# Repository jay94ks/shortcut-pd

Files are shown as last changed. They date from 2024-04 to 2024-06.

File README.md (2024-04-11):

# Simple Shortcut Keypad.
 This has six keys that are customizable, and this designed for disabled peoples. I'm working with disabled brother. he's a survivor of car-crash in highway, I don't know details. A few days ago, I asked him how to press `Ctrl + Alt + Del` key combinations, he answered that "I've gave up to press these kind of key combinations, forever". I thought that, if there is a special keyboard to help him, he will never need to give up to press complex key combinations. this project is for that.
 of course, this is also for gamers and quick `NSFW`, haha!

## Boards
This project is consisted of two boards. one is a USB hub port and `RP2040` board and other one is keypad board. this two boards are connected through `FPC` cable. and fixed by steel bolt bars.

### Lower board
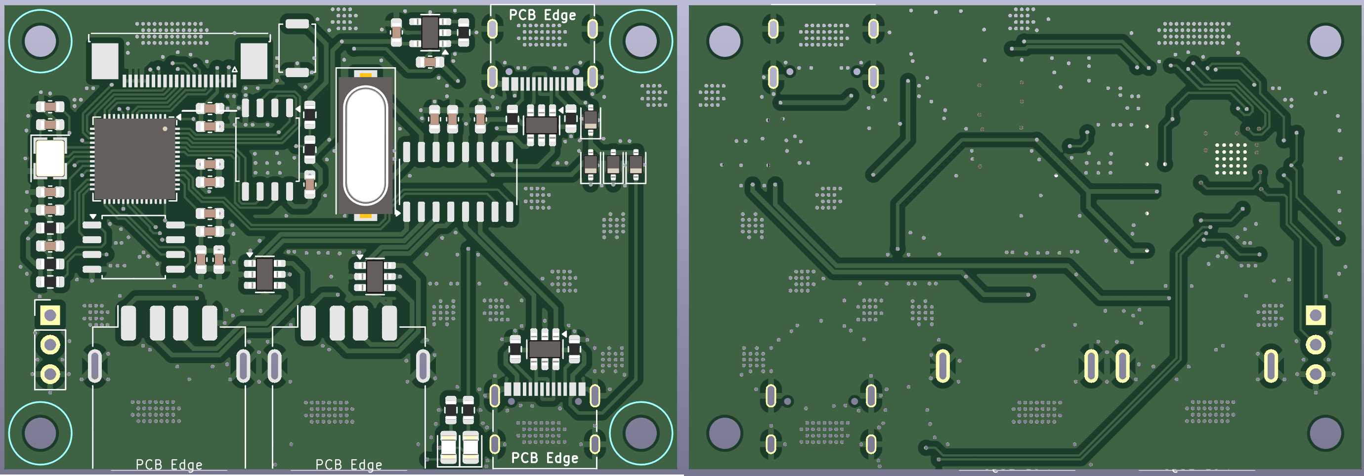
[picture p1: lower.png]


### Upper board
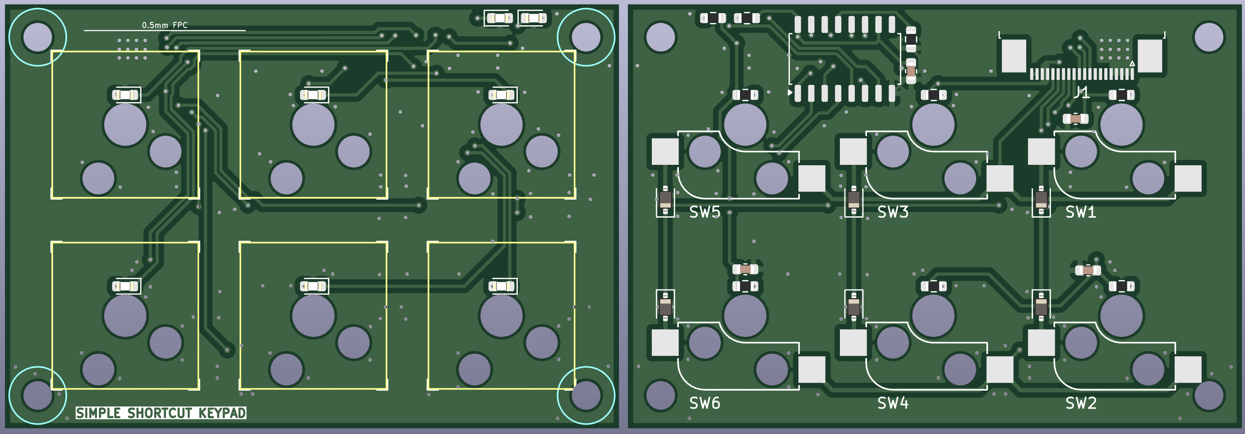
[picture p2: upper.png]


### Assembly diagram
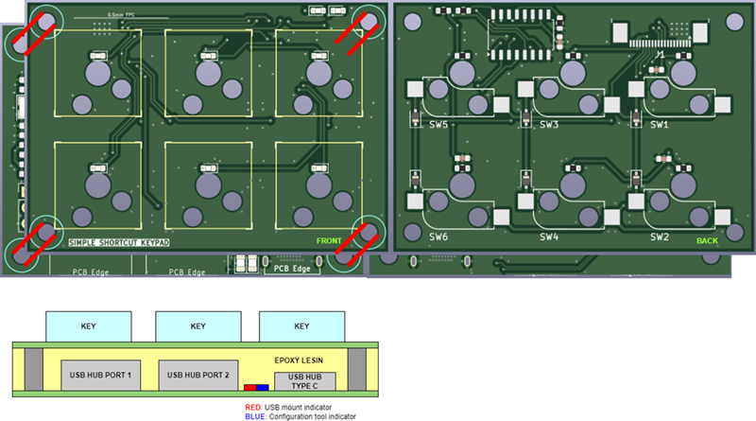
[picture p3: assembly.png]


## Firmware
Work in progress

## Configuration Tool
Work in progress

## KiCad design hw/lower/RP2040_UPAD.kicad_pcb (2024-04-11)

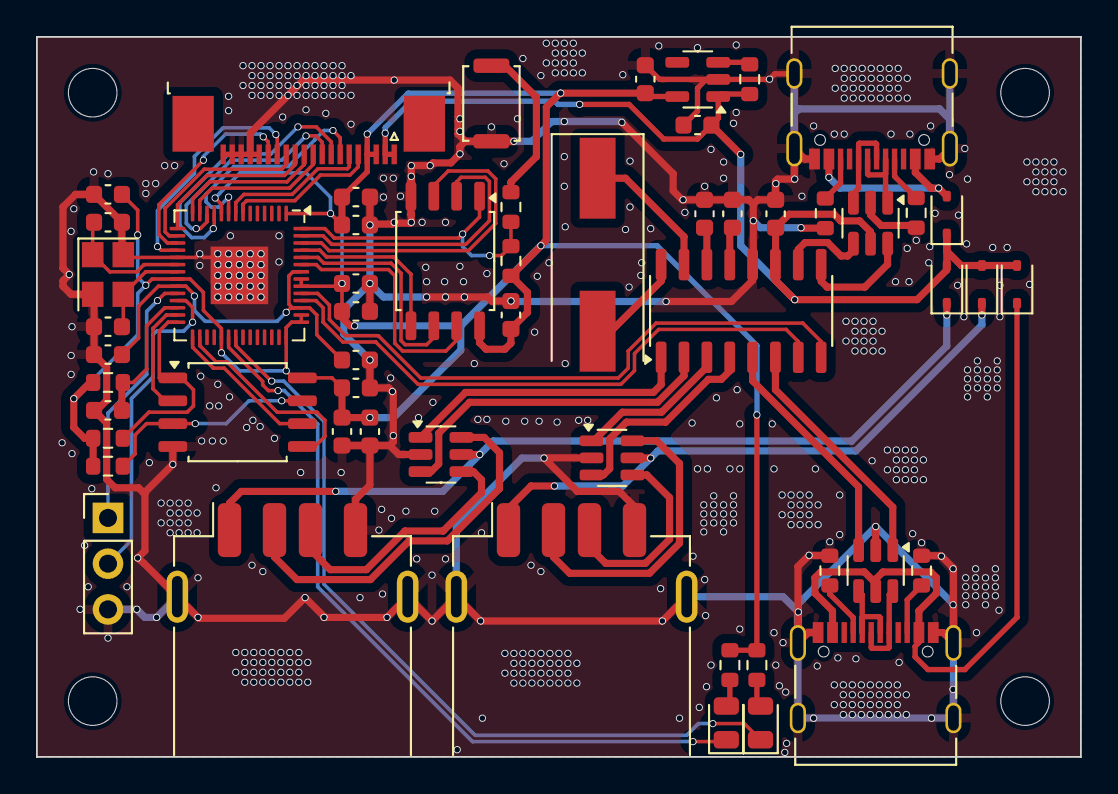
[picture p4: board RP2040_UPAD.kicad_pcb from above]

Board: 2 copper layers, 58.0 x 40.0 mm, 59 parts (0 on the bottom side), 67 nets.

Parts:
C1, C8, C9, C10, C11, C13, C14, C15, C16: 100nF; C_0603_1608Metric
C2, C3: 30pF; C_0603_1608Metric
C5, C6, C7: 2.2uF; C_0603_1608Metric
C17, C18, C19, C20, C21: 10uF; C_0603_1608Metric
D1: LED/R; LED_0805_2012Metric
D2: LED/B; LED_0805_2012Metric
D3, D4, D6, D9: 1N5819WS; D_SOD-323
H1, H2, H3, H4: MountingHole; MountingHole_2.7mm_M2.5
J1: JTAG; PinHeader_1x03_P2.54mm_Vertical
J2, J5: USB_C_Receptacle_USB2.0; USB_C_Receptacle_Palconn_UTC16-G
J3, J4: USB_A; USB_A_Receptacle_GCT_USB1046
J6: 0.5mm FPC; TE_2-1734839-0_1x20-1MP_P0.5mm_Horizontal
R3: 100; R_0603_1608Metric
R4, R7, R10, R12: 10k; R_0603_1608Metric
R5, R6: 1k; R_0603_1608Metric
R11: 100k; R_0603_1608Metric
R13, R14, R18, R19: 5.1k; R_0603_1608Metric
SW1: SW_Push; SW_Push_SPST_NO_Alps_SKRK
U1: RP2040; QFN-56-1EP_7x7mm_P0.4mm_EP3.2x3.2mm
U2: W25Q128JVSS; SOIC-8_5.23x5.23mm_P1.27mm
U3: XC6220B331MR; SOT-23-5
U4: W25Q32JVSS; SOIC-8_5.23x5.23mm_P1.27mm
U5, U11, U12, U13: USBLC6-2SC6; SOT-23-6
U6: SL2.1A; SO-16_3.9x9.9mm_P1.27mm
Y1: 12MHz; Crystal_SMD_3225-4Pin_3.2x2.5mm
Y2: 12MHz; Crystal_SMD_HC49-SD

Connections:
+1V1: C5.2, C6.2, U1.23 (DVDD), U1.45 (VREG_VOUT), U1.50 (DVDD)
+3.3VD: C7.1, C8.1, C9.1, C10.1, C11.1, C13.1, C14.1, C15.1, C16.1, C18.1, J6.3, J6.4, R4.2, R5.2, R6.2, R7.1, R10.2, R12.1, U1.1 (IOVDD), U1.10 (IOVDD), U1.22 (IOVDD), U1.33 (IOVDD), U1.42 (IOVDD), U1.43 (ADC_AVDD), U1.44 (VREG_IN), U1.48 (USB_VDD), U1.49 (IOVDD), U2.8 (VCC), U3.5 (VOUT), U4.8 (VCC)
+5VD: C17.1, C21.1, D3.1 (K), D4.2 (A), D6.2 (A), D9.2 (A), J6.1, J6.2, R11.2, U3.1 (VIN), U5.5 (VBUS), U6.11 (VDD5)
/RP2040/QSPI_SCLK: U1.52 (QSPI_SCLK), U2.6 (CLK)
/RP2040/QSPI_SD0: U1.53 (QSPI_SD0), U2.5 (DI(IO0))
/RP2040/QSPI_SD1: U1.55 (QSPI_SD1), U2.2 (DO(IO1))
/RP2040/QSPI_SD2: U1.54 (QSPI_SD2), U2.3 (IO2)
/RP2040/QSPI_SD3: U1.51 (QSPI_SD3), U2.7 (IO3)
/RP2040/QSPI_SS: R3.1, R7.2, U1.56 (QSPI_SS), U2.1 (~CS)
/USB/USB_RAW_DM: J2.A7 (D-), J2.B7 (D-), U5.1 (I/O1)
/USB/USB_RAW_DP: J2.A6 (D+), J2.B6 (D+), U5.3 (I/O2)
GND: C1.2, C2.1, C3.1, C5.1, C6.1, C7.2, C8.2, C9.2, C10.2, C11.2, C13.2, C14.2, C15.2, C16.2, C17.2, C18.2, C19.1, C20.1, C21.2, J1.3, J2.A1 (GND), J2.A12 (GND), J2.B1 (GND), J2.B12 (GND), J2.S1 (SHIELD), J3.4 (GND), J3.5 (Shield), J4.4 (GND), J4.5 (Shield), J5.A1 (GND), J5.A12 (GND), J5.B1 (GND), J5.B12 (GND), J5.S1 (SHIELD), J6.16, J6.17, J6.18, J6.19, J6.20, R13.2, R14.1, R18.2, R19.1, SW1.1, U1.19 (TESTEN), U1.57 (GND), U2.4 (GND), U3.2 (GND), U4.4 (GND), U5.2 (GND), U6.12 (GND), U11.2 (GND), U12.2 (GND), U13.2 (GND), Y1.2, Y1.4
GP5/ROW1: J6.5, U1.7 (GPIO5)
GP6/ROW2: J6.6, U1.8 (GPIO6)
GP7/COL1: J6.7, U1.9 (GPIO7)
GP8/COL2: J6.8, U1.11 (GPIO8)
GP9/COL3: J6.9, U1.12 (GPIO9)
GP10/SPI1_SCK: J6.10, U1.13 (GPIO10)
GP11/SPI1_TX: J6.11, U1.14 (GPIO11)
GP12/SPI1_RX: J6.12, U1.15 (GPIO12)
GP13/SPI1_CSn: J6.13, U1.16 (GPIO13)
GP14/I2C1_SDA: J6.15, U1.17 (GPIO14)
GP15/I2C1_SCL: J6.14, U1.18 (GPIO15)
GP16/SPI0_RX: U1.27 (GPIO16), U4.2 (DO(IO1))
GP17/SPI0_CSn: R12.2, U1.28 (GPIO17), U4.1 (~CS)
GP18/SPI0_SCK: U1.29 (GPIO18), U4.6 (CLK)
GP19/SPI0_TX: U1.30 (GPIO19), U4.5 (DI(IO0))
GP22/LED_CR: D1.1 (K), U1.34 (GPIO22)
GP23/LED_CE: D2.1 (K), U1.35 (GPIO23)
unnamed: D1.2 (A), R5.1
unnamed: D2.2 (A), R6.1
unnamed: D4.1 (K), J5.A4 (VBUS), J5.A9 (VBUS), J5.B4 (VBUS), J5.B9 (VBUS), U13.5 (VBUS)
unnamed: D6.1 (K), J3.1 (VBUS), U11.5 (VBUS)
unnamed: D9.1 (K), J4.1 (VBUS), U12.5 (VBUS)
unnamed: J2.A5 (CC1), R13.1
unnamed: J2.B5 (CC2), R14.2
unnamed: J3.3 (D+), U11.4 (I/O2)
unnamed: J3.2 (D-), U11.6 (I/O1)
unnamed: J4.3 (D+), U12.4 (I/O2)
unnamed: J4.2 (D-), U12.6 (I/O1)
unnamed: J5.A5 (CC1), R18.1
unnamed: J5.B5 (CC2), R19.2
unnamed: J5.A6 (D+), J5.B6 (D+), U13.6 (I/O1)
unnamed: J5.A7 (D-), J5.B7 (D-), U13.4 (I/O2)
unnamed: R3.2, SW1.2
unnamed: C2.2, U1.20 (XIN), Y1.1
unnamed: C3.2, U1.21 (XOUT), Y1.3
unnamed: R11.1, U3.3 (CE)
unnamed: R10.1, U4.3 (IO2), U4.7 (IO3)
unnamed: C19.2, U6.14 (VDD18)
unnamed: C20.2, U6.13 (VDD33)
unnamed: U6.16 (XIN), Y2.2
unnamed: U6.15 (XOUT), Y2.1
RP2040_DM: U1.46 (USB_DM), U6.7 (DM1)
RP2040_DP: U1.47 (USB_DP), U6.8 (DP1)
RUN: C1.1, R4.1, U1.26 (RUN)
SWD_CLK: J1.1, U1.24 (SWCLK)
SWD_DIO: J1.2, U1.25 (SWD)
USBH1_DM: U6.3 (DM3), U11.1 (I/O1)
USBH1_DP: U6.4 (DP3), U11.3 (I/O2)
USBH2_DM: U6.1 (DM4), U12.1 (I/O1)
USBH2_DP: U6.2 (DP4), U12.3 (I/O2)
USBM2_DM: U6.5 (DM2), U13.3 (I/O2)
USBM2_DP: U6.6 (DP2), U13.1 (I/O1)
USB_DM: U5.6 (I/O1), U6.9 (DM)
USB_DP: U5.4 (I/O2), U6.10 (DP)
VBUS: D3.2 (A), J2.A4 (VBUS), J2.A9 (VBUS), J2.B4 (VBUS), J2.B9 (VBUS)

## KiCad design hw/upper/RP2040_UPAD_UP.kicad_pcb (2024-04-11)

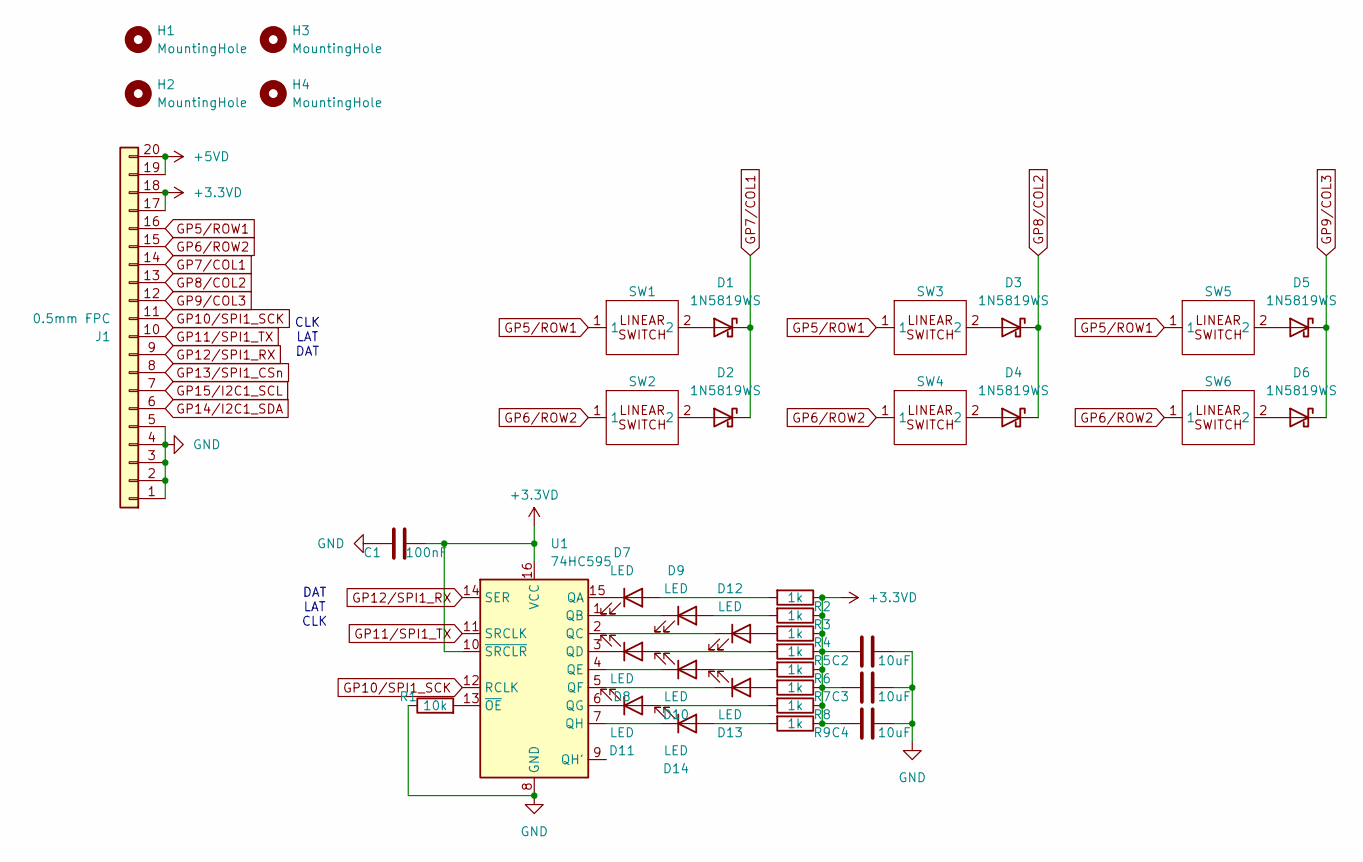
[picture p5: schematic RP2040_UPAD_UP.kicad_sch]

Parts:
C1: 100nF; C_0603_1608Metric
C2, C3, C4: 10uF; C_0603_1608Metric
D1, D2, D3, D4, D5, D6: 1N5819WS; D_SOD-323
D7, D8, D9, D10, D11, D12, D13, D14: LED; LED_0603_1608Metric
H1, H2, H3, H4: MountingHole; MountingHole_2.7mm_M2.5
J1: 0.5mm FPC; TE_2-1734839-0_1x20-1MP_P0.5mm_Horizontal
R1: 10k; R_0603_1608Metric
R2, R3, R4, R5, R6, R7, R8, R9: 1k; R_0603_1608Metric
SW1, SW2, SW3, SW4, SW5, SW6: Kailh_socket_MX_no_throughole
U1: 74HC595; SOP-16_4.55x10.3mm_P1.27mm

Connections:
+3.3VD: C1.2, C2.1, C3.1, C4.1, J1.17, J1.18, R2.1, R3.1, R4.1, R5.1, R6.1, R7.1, R8.1, R9.1, U1.10 (~SRCLR), U1.16 (VCC)
+5VD: J1.19, J1.20
GND: C1.1, C2.2, C3.2, C4.2, J1.1, J1.2, J1.3, J1.4, J1.5, R1.1, U1.8 (GND)
GP5/ROW1: J1.16, SW1.1, SW3.1, SW5.1
GP6/ROW2: J1.15, SW2.1, SW4.1, SW6.1
GP7/COL1: D1.1 (K), D2.1 (K), J1.14
GP8/COL2: D3.1 (K), D4.1 (K), J1.13
GP9/COL3: D5.1 (K), D6.1 (K), J1.12
GP10/SPI1_SCK: J1.11, U1.12 (RCLK)
GP11/SPI1_TX: J1.10, U1.11 (SRCLK)
GP12/SPI1_RX: J1.9, U1.14 (SER)
GP13/SPI1_CSn: J1.8
GP14/I2C1_SDA: J1.6
GP15/I2C1_SCL: J1.7
unnamed: D1.2 (A), SW1.2
unnamed: D2.2 (A), SW2.2
unnamed: D3.2 (A), SW3.2
unnamed: D4.2 (A), SW4.2
unnamed: D5.2 (A), SW5.2
unnamed: D6.2 (A), SW6.2
unnamed: D7.2 (A), R2.2
unnamed: D7.1 (K), U1.15 (QA)
unnamed: D8.2 (A), R5.2
unnamed: D8.1 (K), U1.3 (QD)
unnamed: D9.2 (A), R3.2
unnamed: D9.1 (K), U1.1 (QB)
unnamed: D10.2 (A), R6.2
unnamed: D10.1 (K), U1.4 (QE)
unnamed: D11.2 (A), R8.2
unnamed: D11.1 (K), U1.6 (QG)
unnamed: D12.2 (A), R4.2
unnamed: D12.1 (K), U1.2 (QC)
unnamed: D13.2 (A), R7.2
unnamed: D13.1 (K), U1.5 (QF)
unnamed: D14.2 (A), R9.2
unnamed: D14.1 (K), U1.7 (QH)
unnamed: R1.2, U1.13 (~OE)

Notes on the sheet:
CLK LAT DAT
DAT LAT CLK

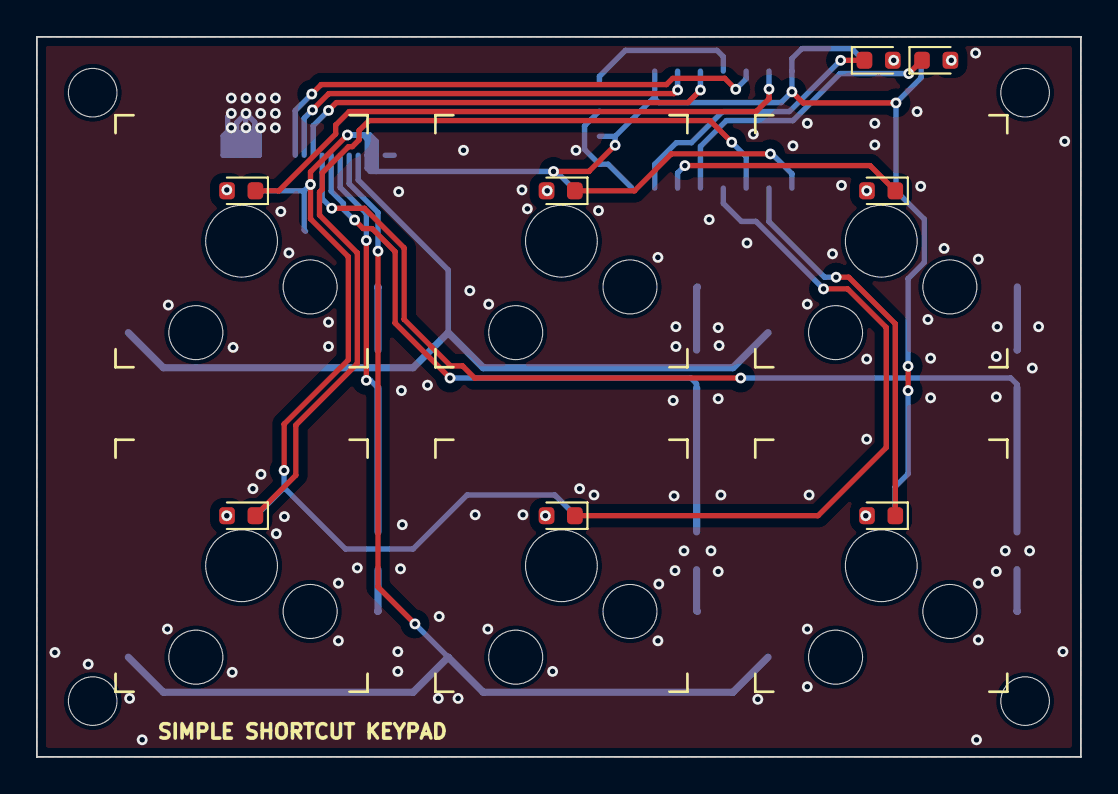
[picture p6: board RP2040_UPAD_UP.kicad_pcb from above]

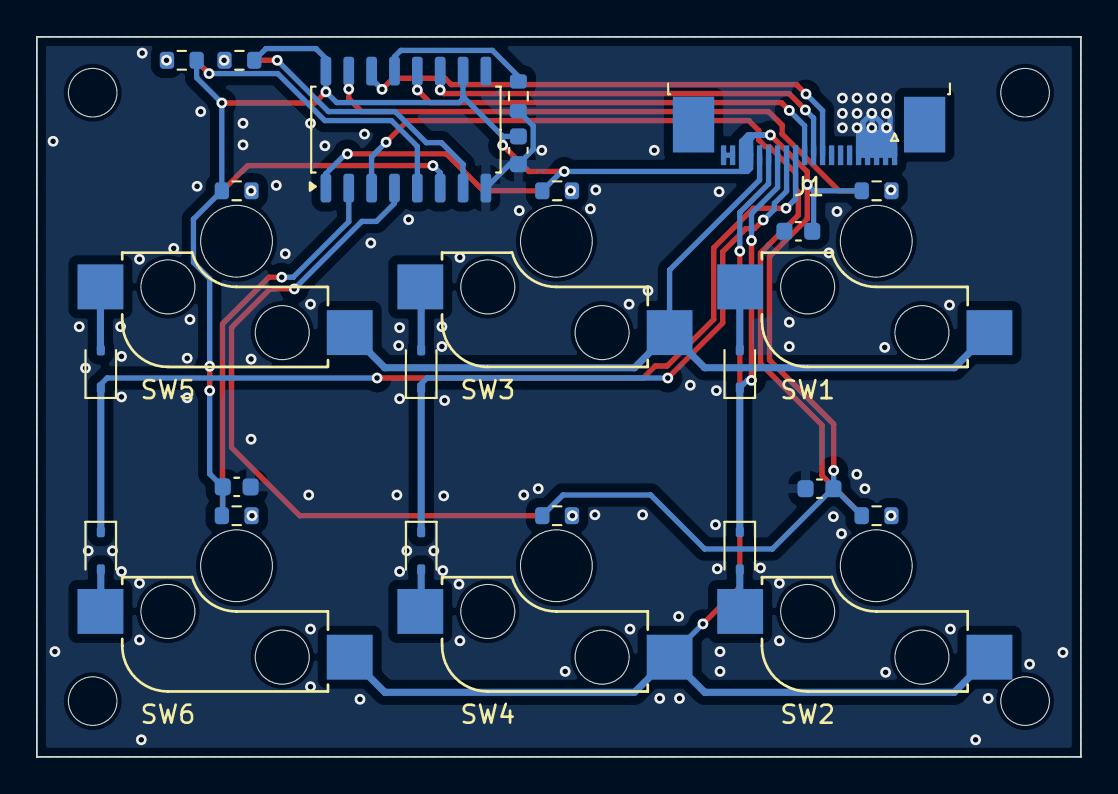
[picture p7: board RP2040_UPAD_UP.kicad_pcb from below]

Board: 2 copper layers, 58.0 x 40.0 mm, 39 parts (21 on the bottom side), 34 nets.

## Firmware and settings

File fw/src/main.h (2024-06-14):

#ifndef __MAIN_H__
#define __MAIN_H__

enum {

    EGPIO_ROW1 = 5,
    EGPIO_ROW2 = 6,
    EGPIO_COL1 = 7,
    EGPIO_COL2 = 8,
    EGPIO_COL3 = 9,

    EGPIO_595_LAT = 10,
    EGPIO_595_CLK = 11,
    EGPIO_595_DAT = 12,

    EGPIO_SPI0_RX = 16,
    EGPIO_SPI0_CSn = 17,
    EGPIO_SPI0_SCK = 18,
    EGPIO_SPI0_TX = 19,

    EGPIO_LED_CR = 22,      // --> USB mount.
    EGPIO_LED_CE = 23,      // --> USB config.

    EGPIO_VSENS = 29
    
};

enum EKey {
    EKEY_00 = 0,
    EKEY_01,
    EKEY_02,
    EKEY_10,
    EKEY_11,
    EKEY_12,
    EKEY_MAX,
    EKEY_INV = 0xff,
};

enum ELed {
    ELED_00 = 7,
    ELED_01 = 6,
    ELED_02 = 1,
    ELED_10 = 4,
    ELED_11 = 3,
    ELED_12 = 5,
    ELED_TR = 2,    // --> D13. CAPSLOCK
    ELED_TL = 0     // --> D14. NUMLOCK
};

#endif

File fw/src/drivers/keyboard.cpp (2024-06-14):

#include "keyboard.h"
#include <string.h>
#include <hardware/gpio.h>
#include <bsp/board_api.h>

const uint8_t Keyboard::PIN_ROW[MAX_ROW] = {
    EGPIO_ROW1, EGPIO_ROW2
};

const uint8_t Keyboard::PIN_COL[MAX_COL] = {
    EGPIO_COL1, EGPIO_COL2, EGPIO_COL3
};

EKey KeyOrderIterator::operator*() const {
    if (_kbd) {
        return _kbd->getKeyInOrder(_cur);
    }

    return EKEY_INV;
}

Keyboard::Keyboard() {
    for(uint8_t i = 0; i < MAX_ROW; ++i) {
        const uint8_t pin = PIN_ROW[i];

        gpio_init(pin);
        gpio_set_dir(pin, GPIO_OUT);
        gpio_put(pin, 0);
    }

    for(uint8_t i = 0; i < MAX_COL; ++i) {
        const uint8_t pin = PIN_COL[i];

        gpio_init(pin);
        gpio_set_dir(pin, GPIO_IN);
    }

    memset(_next, 0, sizeof(_next));
    memset(_state, 0, sizeof(_state));
    
    _ordered = 0;
    _scantick = 0;

    for(uint8_t i = 0; i < EKEY_MAX; ++i) {
        _orders[i] = EKEY_INV;
    }
}

void Keyboard::scanOnce() {
    const uint32_t now = board_millis();
    if (_scantick != now) {
        _scantick = now;

        memset(_next, 0, sizeof(_next));

        // --> scan line levels.
        for(uint8_t i = 0; i < MAX_ROW; ++i) {
            const uint8_t row = PIN_ROW[i];
            
            gpio_put(row, 1);
            delayNs();

            for(uint8_t j = 0; j < MAX_COL; ++j) {
                const uint8_t mask = 1 << j;

                if (gpio_get(PIN_COL[j])) {
                    _next[i] |= mask;
                }
            }

            gpio_put(row, 0);
            delayNs();
        }
    }
    
    updateOnce();
}

void Keyboard::updateOnce() {
    // --> summarize key changes.
    for(uint8_t row = 0; row < MAX_ROW; ++row) { 
        const uint8_t offset = row * MAX_COL;

        for(uint8_t col = 0; col < MAX_COL; ++col) {
            const EKey key = EKey(offset + col);
            const uint8_t mask = 1 << col;

            const uint8_t prev 
                = _state[key].ls == EKSL_RISE || 
                  _state[key].ls == EKSL_HIGH;

            const uint8_t next = (_next[row] & mask) != 0;
            
            if (prev != next) {
                if (next) {
                    _state[key].ls = EKSL_RISE;
                    addOrder(key);
                } else {
                    _state[key].ls = EKSL_FALL;
                    removeOrder(key);
                }

                _state[key].lt = board_millis();
                continue;
            }

            if (_state[key].ls == EKSL_HIGH ||
                _state[key].ls == EKSL_LOW)
            {
                continue;   
            }

            if (_state[key].ls == EKSL_RISE) {
                _state[key].ls = EKSL_HIGH;
            } else {
                _state[key].ls = EKSL_LOW;
            }
            
            _state[key].lt = board_millis();
        }
    }

    // --> copy and fill keys.
    assignOrders();
}

int32_t Keyboard::findOrder(EKey key) {
    const uint8_t count
        = _ordered > EKEY_MAX
        ? EKEY_MAX : _ordered;

    for(uint8_t i = 0; i < count; ++i) {
        if (_orders[i] == key) {
            return i;
        }
    }

    return -1;
}

void Keyboard::addOrder(EKey key) {
    if (_ordered >= EKEY_MAX) {
        return;
    }

    const uint8_t count
        = _ordered > EKEY_MAX
        ? EKEY_MAX : _ordered;

    removeOrder(key);

    // --> insert the key to front.
    _orders[_ordered++] = key;
}

void Keyboard::removeOrder(EKey key) {
    int32_t n = findOrder(key);
    if (n < 0) {
        return;
    }

    const uint8_t count
        = _ordered > EKEY_MAX
        ? EKEY_MAX : _ordered;

    for (uint8_t i = n; i < count - 1; ++i) {
        _orders[i] = _orders[i + 1];
    }

    _ordered--;
}

void Keyboard::assignOrders() {
    const uint8_t count
        = _ordered > EKEY_MAX
        ? EKEY_MAX : _ordered;

    for (uint8_t i = 0; i < EKEY_MAX; ++i) {
        _state[i].ko = 0xff;
    }
    
    for (uint8_t i = 0; i < count; ++i) {
        const EKey key = _orders[i];
        if (SKey* ptr = getKeyPtr(key)) {
            ptr->ko = i;
        }
    }
}

uint8_t Keyboard::getKeyOrder(EKey key) const {
    if (SKey* ptr = getKeyPtr(key)) {
        return ptr->ko;
    }

    return 0xff;
}

EKey Keyboard::getKeyInOrder(uint8_t order) const {
    const uint8_t count
        = _ordered > EKEY_MAX
        ? EKEY_MAX : _ordered;

    if (order >= count) {
        return EKEY_INV;
    }

    return _orders[order];
}

uint8_t Keyboard::getKeys(EKeyState state, EKey* buf, uint8_t max) const {
    if (max > EKEY_MAX) {
        max = EKEY_MAX;
    }

    if (max <= 0) {
        return 0;
    }
    
    uint8_t index = 0;
    for(uint8_t key: _orders) {
        if (index >= max) {
            break;
        }

        buf[index++] = EKey(key);
    }

    return index;
}

SKey *Keyboard::getKeyPtr(EKey key) const {
    if (key >= EKEY_MAX) {
        return nullptr;
    }

    return &_state[key];
}
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
